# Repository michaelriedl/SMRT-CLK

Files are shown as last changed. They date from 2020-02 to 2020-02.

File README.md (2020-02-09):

<p align="center">
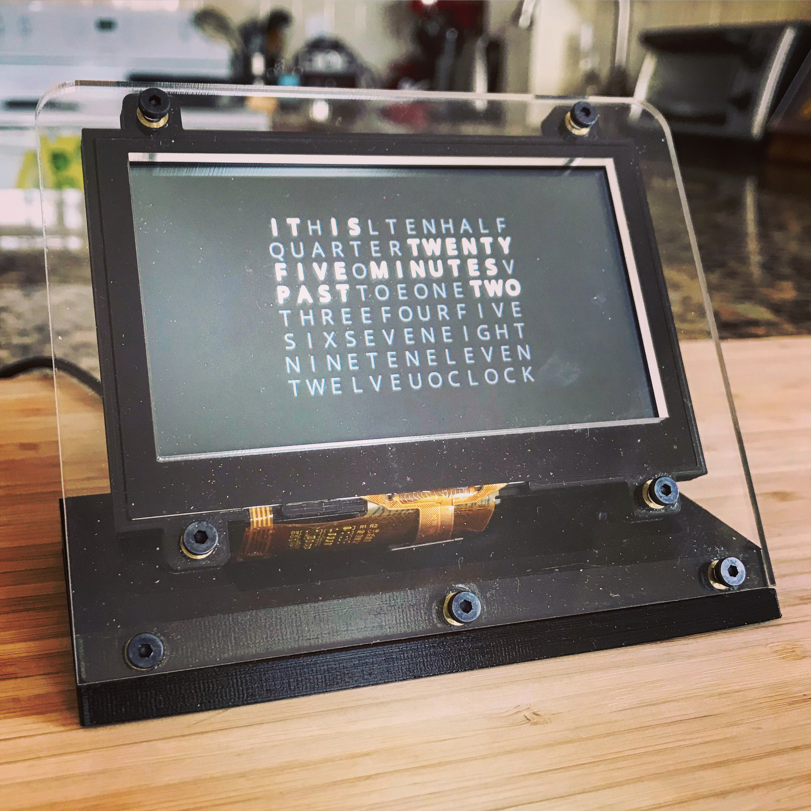
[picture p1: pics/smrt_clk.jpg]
BatBone
  
</p>

# SMRT-CLK
Smart clock / dashboard based on the Raspberry Pi. 

## Building the SMRT CLK
This section will cover the materials and steps needed to build the SMRT CLK.

### Order the PCB
The first step is to order the PCB. You can use the schematics to order the board from your favorite PCB manufacturer or you can use the link below to order it from OSH Park. 



### Order the Parts
Next you'll need to order the parts using the bill of materials spreadsheet in the */bom/* folder. You can upload the BOM straight to DigiKey and order the parts all at once. You will also need to order some parts from McMaster Carr. The links to the parts are as follows:
+ <https://www.mcmaster.com/94180A331>
+ <https://www.mcmaster.com/94180A307>
+ <https://www.mcmaster.com/93070A064>
+ <https://www.mcmaster.com/93070a275>

### Assembling the PCB
Assembing the PCB is easiest using solder paste and a hot air reflow station. You can refer to the board schematic for component placement. The most difficult component is the 40 pin connector for the screen due to the fine pitch of the pins. Once the PCB is assembled you will need to solder the PCB to the Raspberry Pi Zero. I found that this was easiest to do by first using the screws and brass inserts to hold the PCB to the Pi once the pads are aligned and then using the solder paste syringe to put the paste into the through-hole pins on the Pi. The two can then be reflowed with a hot air reflow station.

### Building the Case
To build the case you will need to 3D print two parts and cut another two parts out of 3mm acrylic. I have included STL files for the parts that need to be printed and an EPS file for the parts that need to be cut. If you do not have access to a laser cutter, I have used <https://ponoko.com> in the past and was really happy with the results.

Once the parts are 3D printed, you will need to sink the brass heated inserts into the parts with a soldering iron. This should be pretty straight forward. There are plenty of videos and guides on the interenet if you need an example of how to set the inserts.

Final assembly of the SMRT CLK should be easy. I would suggest assembling the SMRT CLK in this order:
1. Attach the screen's ribbon cables to the PCB.
2. Secure the Pi into the 3D printed base using the screws.
3. Attach the acrylic lid to the 3D printed base using the screws.
4. Attach the acrylic screen mount to the base using the screws.
5. Place the screen in the 3D printed screen mount and attach it to the acrylic screen mount with the screws.

## Setting Up the SMRT CLK
There are just a few files that need to be copied to the Pi itself and then some of them need to be compiled. These files are located in the */distro/* folder. We will start first with the device tree overlays which need to be transfered to the Pi and compiled.

### Device Tree Overlays
I have written some device tree settings that need to be compiled into device tree overlays and placed in the proper folder. The overlays do the following:
1. *dpi565.dts* - This sets the GPIO that we use for the screen to their alternate function which is DPI output.
2. *pullup.dts* - This sets the pullup resistors for the GPIO pins that we are using for I2C. We are using I2C to communicate with the touch screen controller.
3. *touchscreen.dts* - This sets the driver to use with the I2C touch controller. It also registers a GPIO pin to use as a hardware interrupt for the touch controller.
The device tree overlays should be compiled with the following commands:
```
sudo dtc -I dts -O dtb -o /boot/overlays/dpi565.dtbo dpi565.dts
sudo dtc -I dts -O dtb -o /boot/overlays/pullup.dtbo pullup.dts
sudo dtc -I dts -O dtb -o /boot/overlays/touchscreen.dtbo touchscreen.dts
```

### Boot Configuration
I also have included a *config.txt* that should replace the existing one in the Raspbian */boot/* folder. The purpose of the file configuration file is to tell Raspbian to load the device tree overlays we compiled. Additionally, the configuration file has the settings (resolution, timings, etc...) for the LCD display.

### Touch Screen Calibration
Once the device tree overlays and boot configuration are properly setup, the display and touch screen should work after rebooting the Pi. The final step is to calibrate the touch screen. I found these calibration values through trial and error. Eventually I would like to write a script that does the calibration by having the user touch calibration points on the screen. The screen can be calibrated with the following commands:
```
DISPLAY=:0 xinput set-prop 'EP0790M09' 'Coordinate Transformation Matrix' 1 0 -1 0 1 0 0 0 1
DISPLAY=:0 xinput set-prop 'EP0790M09' 'libinput Calibration Matrix' 6.5 0 1 0 10 0 0 0 1
```
This calibration only lasts as long as the Pi is on. To make the calibration permanent, the commands need to be placed in a script and executed once the Pi is on and the device tree overlays have been loaded. There are various ways to do this depending on your application and version of Raspbian.

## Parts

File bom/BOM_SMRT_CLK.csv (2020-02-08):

Manufacturer Part Number | Manufacturer | Digi-Key Part Number | Customer Reference | Reference Designator | Packaging | Part Status | Quantity | Unit Price | Extended Price | Quantity Available | Mfg Std Lead Time | Description | RoHS Status | Lead Free Status | REACH Status
FAN5333BSX | ON Semiconductor | FAN5333BSXCT-ND |  |  | Cut Tape (CT) | Active | 1 | 0.99000 | $0.99 | 10107 | 38 Weeks | IC LED DRIVER RGLTR DIM SOT23-5 | ROHS3 Compliant | Lead free | REACH Unaffected
MBR0540 | ON Semiconductor | MBR0540CT-ND |  |  | Cut Tape (CT) | Active | 1 | 0.33000 | $0.33 | 249589 | 20 Weeks | DIODE SCHOTTKY 40V 500MA SOD123 | ROHS3 Compliant | Lead free | REACH Unaffected
SMAZ24-TP | Micro Commercial Co | SMAZ24-TPMSCT-ND |  |  | Cut Tape (CT) | Active | 1 | 0.42000 | $0.42 | 17598 | 12 Weeks | DIODE ZENER 24V 1W DO214AC | ROHS3 Compliant | Lead free | REACH Unaffected
ASPI-0615FS-6R8M-T2 | Abracon LLC | 535-10777-1-ND |  |  | Cut Tape (CT) | Active | 1 | 0.77000 | $0.77 | 5337 | 15 Weeks | FIXED IND 6.8UH 1.8A 60 MOHM SMD | RoHS Compliant | Lead free | REACH Unaffected
NHD-4.3-480272EF-ASXN#-CTP | Newhaven Display Intl | NHD-4.3-480272EF-ASXN#-CTP-ND |  |  | Bulk | Active | 1 | 64.93000 | $64.93 | 78 | 18 Weeks | LCD 4.3"TFT CAP TOUCH SUNL READ | RoHS Compliant | Lead free | REACH Unaffected
0522710679 | Molex | WM7955CT-ND |  |  | Cut Tape (CT) | Active | 1 | 0.99000 | $0.99 | 10457 | 8 Weeks | CONN FPC BOTTOM 6POS 1.00MM R/A | ROHS3 Compliant | Lead free | REACH Unaffected
0541044031 | Molex | WM3431CT-ND |  |  | Cut Tape (CT) | Active | 1 | 2.94000 | $2.94 | 12516 | 10 Weeks | CONN FFC TOP 40POS 0.50MM R/A | ROHS3 Compliant | Lead free | REACH Unaffected
RC0805FR-0712RL | Yageo | 311-12.0CRCT-ND |  |  | Cut Tape (CT) | Active | 1 | 0.10000 | $0.10 | 205143 | 33 Weeks | RES SMD 12 OHM 1% 1/8W 0805 | ROHS3 Compliant | Lead free | REACH Unaffected
RMCF0805FT10K0 | Stackpole Electronics Inc | RMCF0805FT10K0CT-ND |  |  | Cut Tape (CT) | Active | 1 | 0.10000 | $0.10 | 3783996 | 17 Weeks | RES 10K OHM 1% 1/8W 0805 | ROHS3 Compliant | Lead free | REACH Unaffected
GCM21BR7YA105KA55L | Murata Electronics | 490-5320-1-ND |  |  | Cut Tape (CT) | Active | 2 | 0.40000 | $0.80 | 575035 | 15 Weeks | CAP CER 1UF 35V X7R 0805 | ROHS3 Compliant | Lead free | Not Available
CL21A106KPFNNNE | Samsung Electro-Mechanics | 1276-1052-1-ND |  |  | Cut Tape (CT) | Active | 1 | 0.14000 | $0.14 | 541732 | 22 Weeks | CAP CER 10UF 10V X5R 0805 | ROHS3 Compliant | Lead free | REACH Unaffected
C0805C104K6RAC7800 | KEMET | 399-17618-1-ND |  |  | Cut Tape (CT) | Active | 1 | 0.55000 | $0.55 | 2323 | 8 Weeks | CAP CER SMD 0805 .1UF 35V 10% X7 | ROHS3 Compliant | Lead free | REACH Unaffected

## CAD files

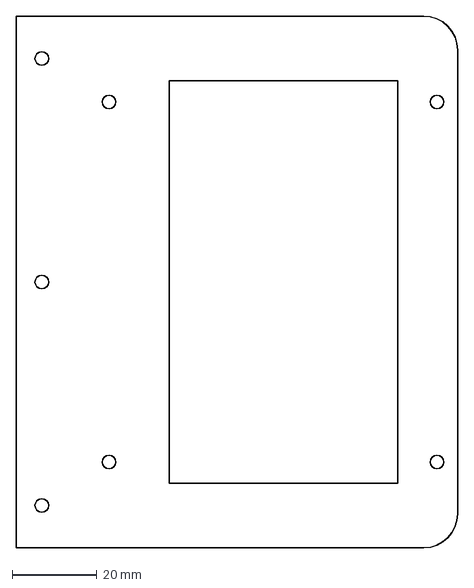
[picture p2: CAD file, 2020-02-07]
case/acrylic/dxf/Front_Plate.dxf
104.2 x 125.5 mm

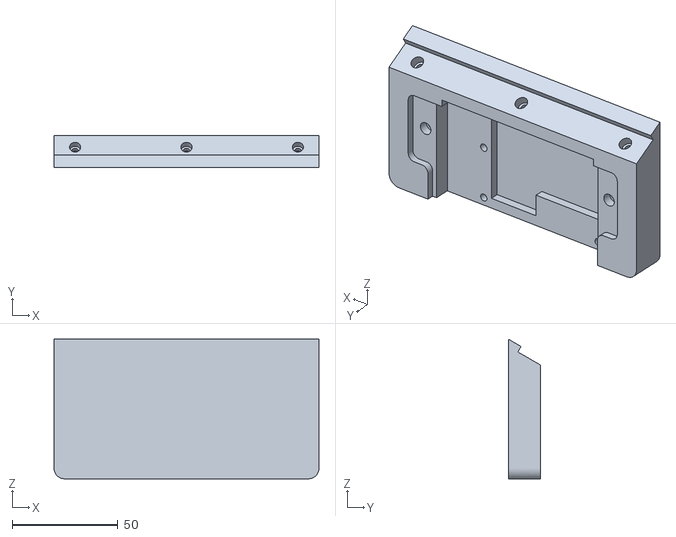
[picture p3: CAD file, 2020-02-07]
case/stl/Base.stl
125.5 x 15.2 x 66.1

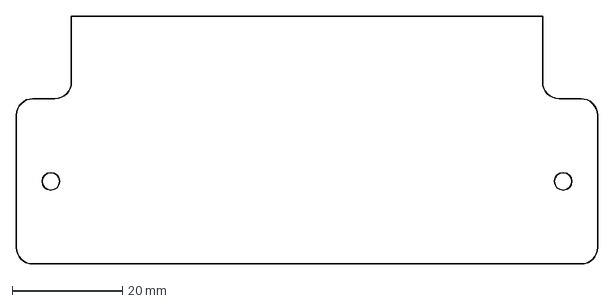
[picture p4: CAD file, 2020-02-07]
case/acrylic/dxf/Lid.dxf
105.5 x 45.0 mm

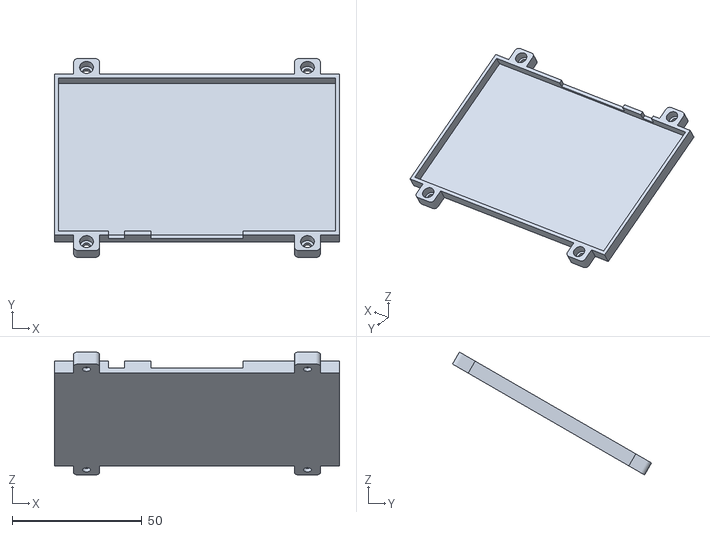
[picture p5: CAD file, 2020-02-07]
case/stl/Screen_Mount.stl
109.7 x 76.6 x 47.3

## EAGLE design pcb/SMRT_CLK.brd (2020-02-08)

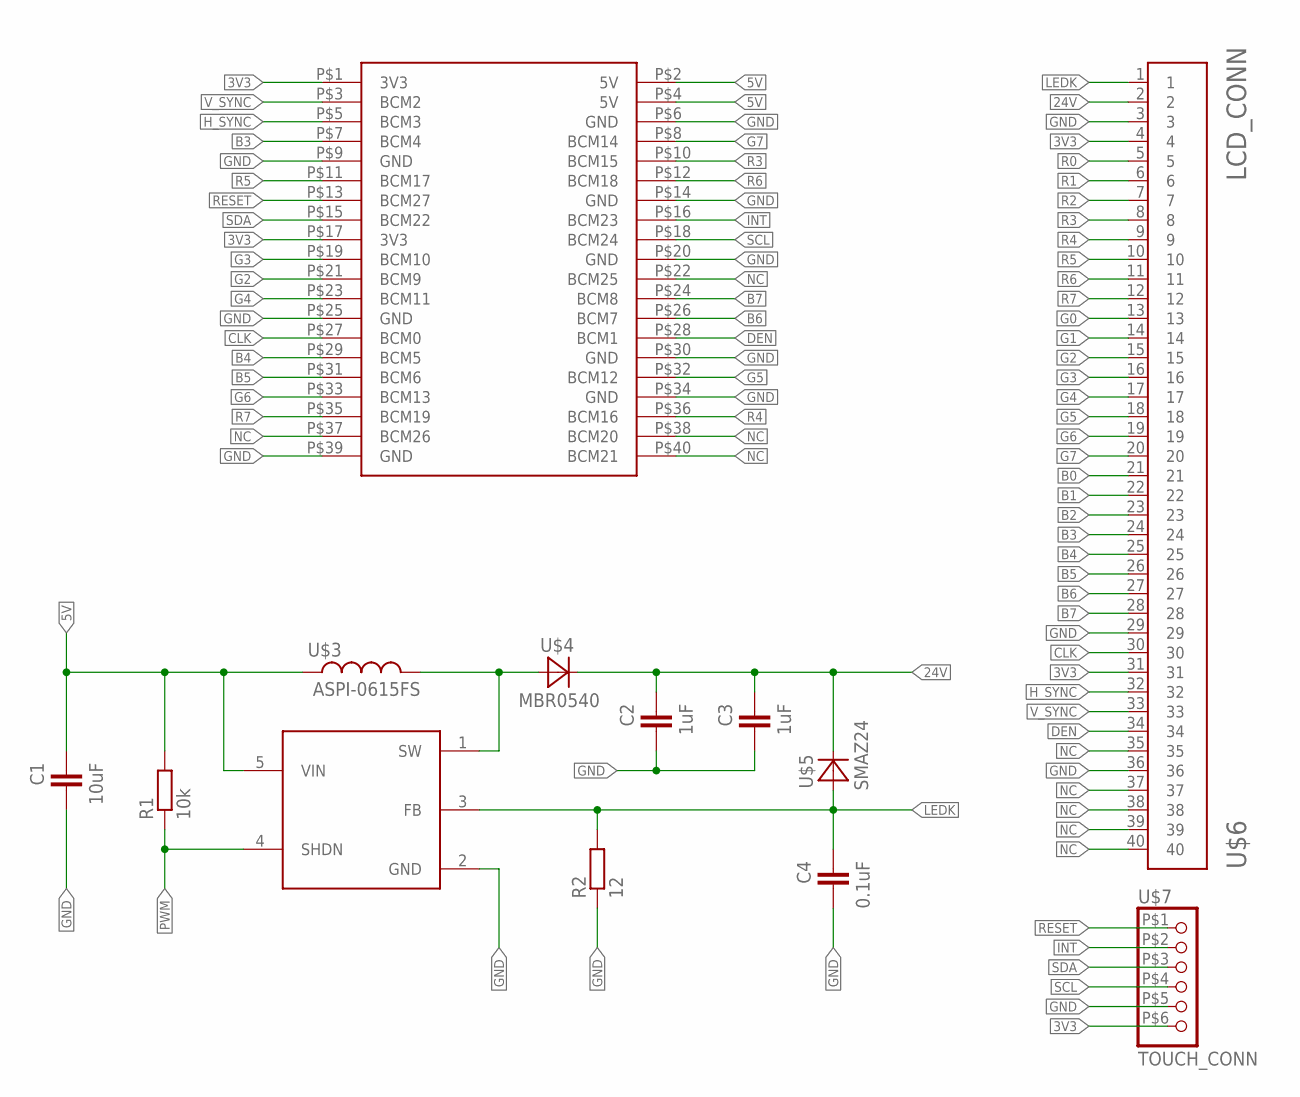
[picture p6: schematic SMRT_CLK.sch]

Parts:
C1: 10uF; C0805
C2, C3: 1uF; C0805
C4: 0.1uF; C0805
R1: 10k; R0805
R2: 12; R0805
U$1: SMRT_CLK; FULL_BOARD
U$2: FAN5333BSX; SOT23-5
U$3: ASPI-0615FS; CUST_IND
U$4: MBR0540; SOD-123_MINI-SMA
U$5: SMAZ24; DO-214AC
U$6: LCD_CONN; 4-1734839-0
U$7: TOUCH_CONN; 052207

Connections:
3V3: U$1.P$1 (3V3), U$1.P$17 (3V3), U$6.4, U$6.31, U$7.P$6 (6)
5V: C1.2, R1.2, U$1.P$2 (5V), U$1.P$4 (5V), U$2.5 (VIN), U$3.P$1 (1)
24V: C2.2, C3.2, U$4.C, U$5.C, U$6.2
B0: U$6.21
B1: U$6.22
B2: U$6.23
B3: U$1.P$7 (BCM4), U$6.24
B4: U$1.P$29 (BCM5), U$6.25
B5: U$1.P$31 (BCM6), U$6.26
B6: U$1.P$26 (BCM7), U$6.27
B7: U$1.P$24 (BCM8), U$6.28
CLK: U$1.P$27 (BCM0), U$6.30
DEN: U$1.P$28 (BCM1), U$6.34
G0: U$6.13
G1: U$6.14
G2: U$1.P$21 (BCM9), U$6.15
G3: U$1.P$19 (BCM10), U$6.16
G4: U$1.P$23 (BCM11), U$6.17
G5: U$1.P$32 (BCM12), U$6.18
G6: U$1.P$33 (BCM13), U$6.19
G7: U$1.P$8 (BCM14), U$6.20
GND: C1.1, C2.1, C3.1, C4.1, R2.1, U$1.P$6 (GND), U$1.P$9 (GND), U$1.P$14 (GND), U$1.P$20 (GND), U$1.P$25 (GND), U$1.P$30 (GND), U$1.P$34 (GND), U$1.P$39 (GND), U$2.2 (GND), U$6.3, U$6.29, U$6.36, U$7.P$5 (5)
H_SYNC: U$1.P$5 (BCM3), U$6.32
INT: U$1.P$16 (BCM23), U$7.P$2 (2)
LEDK: C4.2, R2.2, U$2.3 (FB), U$5.A, U$6.1
unnamed: U$2.1 (SW), U$3.P$2 (2), U$4.A
NC: U$1.P$22 (BCM25), U$1.P$37 (BCM26), U$1.P$38 (BCM20), U$1.P$40 (BCM21), U$6.35, U$6.37, U$6.38, U$6.39, U$6.40
PWM: R1.1, U$2.4 (SHDN)
R0: U$6.5
R1: U$6.6
R2: U$6.7
R3: U$1.P$10 (BCM15), U$6.8
R4: U$1.P$36 (BCM16), U$6.9
R5: U$1.P$11 (BCM17), U$6.10
R6: U$1.P$12 (BCM18), U$6.11
R7: U$1.P$35 (BCM19), U$6.12
RESET: U$1.P$13 (BCM27), U$7.P$1 (1)
SCL: U$1.P$18 (BCM24), U$7.P$4 (4)
SDA: U$1.P$15 (BCM22), U$7.P$3 (3)
V_SYNC: U$1.P$3 (BCM2), U$6.33

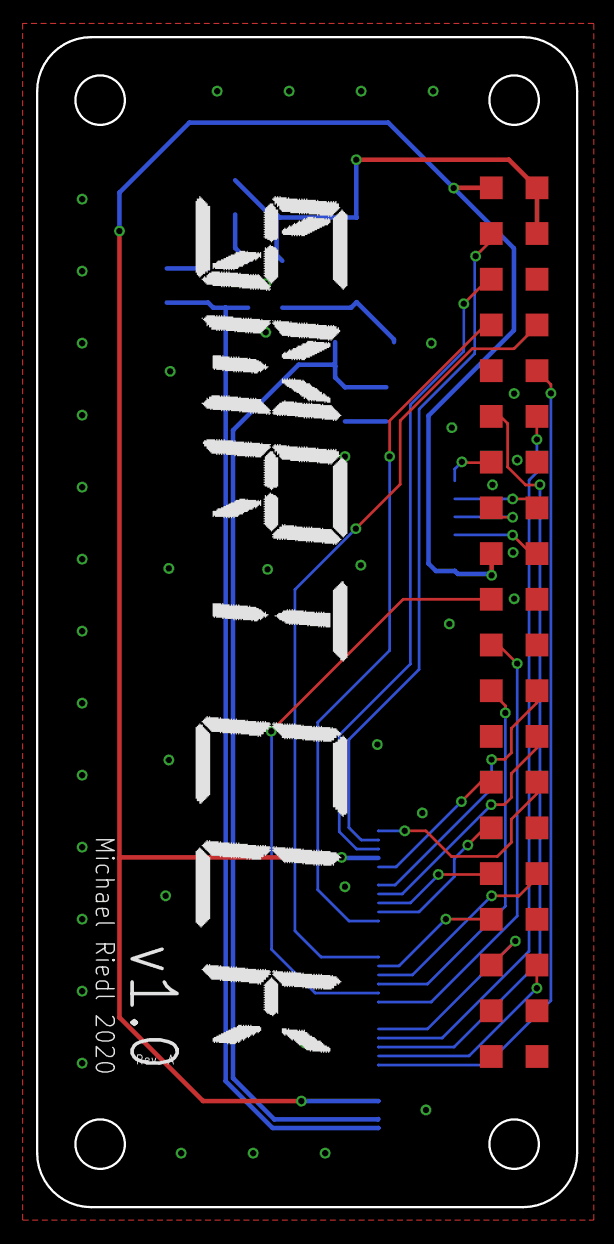
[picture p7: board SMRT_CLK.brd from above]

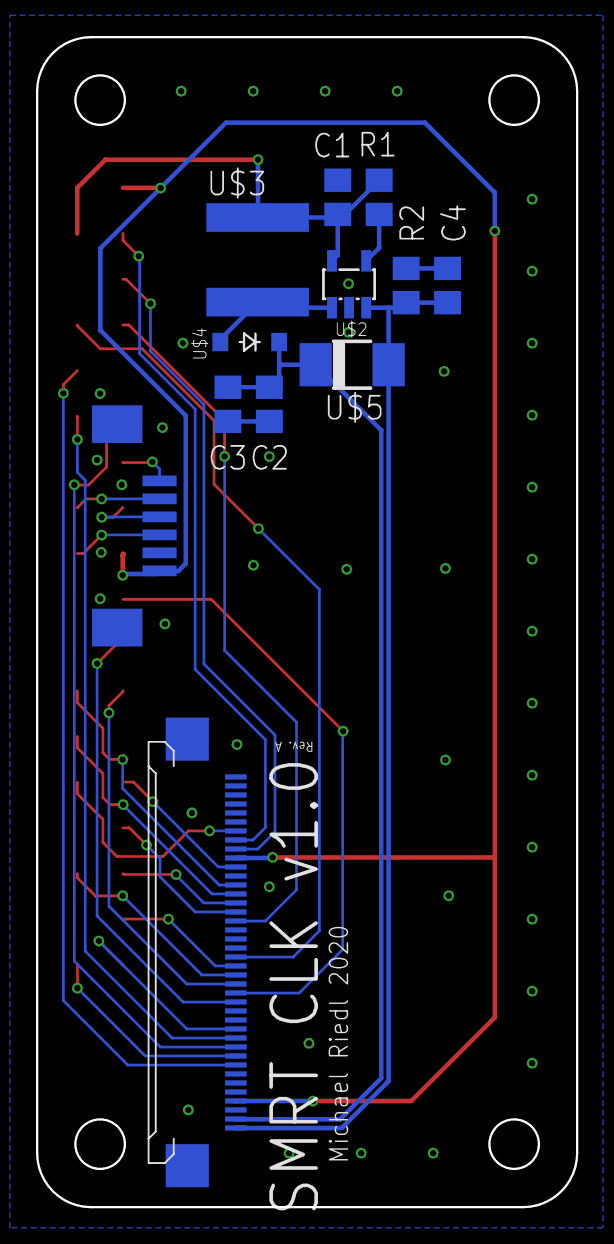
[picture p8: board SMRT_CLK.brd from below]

Board: 2 copper layers, 30.0 x 65.0 mm, 13 parts (12 on the bottom side), 32 nets.

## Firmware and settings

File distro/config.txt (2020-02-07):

# For more options and information see
# http://rpf.io/configtxtreadme
# Some settings may impact device functionality. See link above for details

dtoverlay=dpi565
dtoverlay=i2c-gpio,i2c_gpio_sda=22,i2c_gpio_scl=24,i2c_gpio_delay_us=2
dtoverlay=pullup
dtoverlay=touchscreen

# Enable audio (loads snd_bcm2835)
#dtparam=audio=on
#dtparam=spi=off

overscan_left=0
overscan_right=0
overscan_top=0
overscan_bottom=0
framebuffer_width=480
framebuffer_height=272
enable_dpi_lcd=1
display_default_lcd=1
dpi_group=2
dpi_mode=87
dpi_output_format=0x6f002
hdmi_timings=480 0 2 41 2 272 0 2 10 2 0 0 0 73 0 9600000 3
overscan_scale=1

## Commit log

2020-02-07 Initial dump
    [Base.stl, Front_Plate.dxf, Lid.dxf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]
2020-02-08 Added PCB
    [SMRT_CLK.brd, SMRT_CLK.sch]
